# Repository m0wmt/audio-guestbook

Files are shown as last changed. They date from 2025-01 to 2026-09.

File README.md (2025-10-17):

# audio-guestbook
Audio guestbook for an upcoming wedding.  Let guests leave a message so the bride and groom can relive the day and hear what their loved ones/friends had to say via an old BT rotary telephone (using a Teensy development board and a Teensy Audio board) to record messages to a micro SD card.

This project is an update (VSCode + PlatformIO VS Arduino IDE) of the audio guestbook project by [Playful Technology](https://github.com/playfultechnology/audio-guestbook).

## Technical 

### Code Editor
VSCode using the following plugins:
  * PlatformIO
  * Clang-Format (code formatting) with a bespoke .clang-format file

### Coding Standards
Using the [Barr Group](https://barrgroup.com/sites/default/files/barr_c_coding_standard_2018.pdf) embedded C coding standards. Unable to adhere 100% due to clang-format issues and personal preferences, e.g. line length which I prefer to be 120 wide.

### Audio Library
As mentioned in the JOURNAL, the PJRC forum thread on the audio guestbook noted that increasing the number of audio samples in an "audio block" from 128 to 256 mean less writes to the SD card. Audio updates run every 5.8ms rather than the standard 2.9ms, with the consequence that an SD write can take nearly 12ms before an update is "lost".

### Support Projects
- rtc-test Quick test of the RTC with a button battery.
- button-test Poject to test the logic of the audio guestbook without having to worry about messing up the main project.
- admin-monitor An ESP32 project (in progress) that will be used to monitor the status of the audio guestbook via wi-fi. Will only be available if the venue has mains power due to the power demands of wi-fi draining a battery too quickly.

## Requirements
- Power switch to turn recorder on/off
- Start recording when handset is lifted
- Stop recording when handset is replaced
- Light to indicate when recording?
- Maximum recording length of 'n' minutes
- Stop recording after set time, play time exceeded .wav file
- Deal with handset not being put back correctly (see exceed recording length)
- Light to inidicate errors (different colours for different errors)?
- Play recorded message to tell user 'to leave their message after the beep'
- Get recorded message(s) from customer (start recording, exceeding time limit, and contact support)
- Button to replay last message
- Save recorded messages as .wav files to micro SD card
- Indicate how many messages have been recorded (to be defined)
- Power recorder by USB phone charger or battery
- Web page showing status (number of recordings, disk usage etc.) to support user. This will utilize an ESP32 with a Wi-Fi access point, with messages sent via Serial/UART from the Teensy to the ESP32 for displaying. Due to power demand of the wi-fi this will only be available if we're using mains power.

## Parts List
- Rotary telephone [how to dismantle GPO No. 706 Rotary Phone](https://www.britishtelephones.com/t706dismantle.htm)
- Teensy 4.1 [development board](https://www.pjrc.com/teensy/pinout.html)
- Teensy 4.0 [audio board](https://www.pjrc.com/store/teensy3_audio.html)
- Mico SD card (7.2Gb for 24hrs @ 44.1kHz)
- LED light(s)?
- Switch
- ESP32-S3 Mini (Admin Monitor Website)
- [Electret](https://en.wikipedia.org/wiki/Electret_microphone) microphone
- [My 3D model](https://github.com/m0wmt/audio-guestbook/blob/main/notes/GPO706-Electret-Mic.stl) (.stl) of electret microphone housing

<figure>
  <figcaption>Teensy 4.1</figcaption>
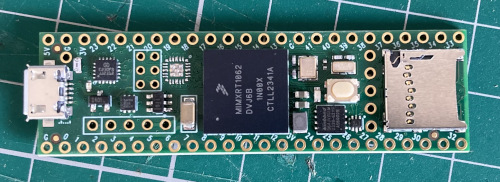
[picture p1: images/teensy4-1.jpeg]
Teensy 4.1 Development Board
  
</figure>

<figure>
  <figcaption>Teensy Audio Board 4.0</figcaption>
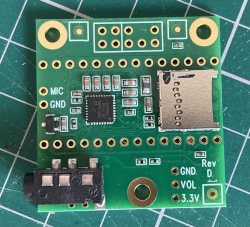
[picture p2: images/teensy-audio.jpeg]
Teensy 4.0 Audio Board
  
</figure>

<figure>
  <figcaption>ESP32-S3 Mini</figcaption>
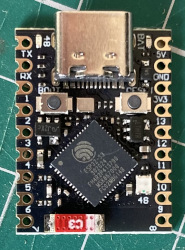
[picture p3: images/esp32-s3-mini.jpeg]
ESP32-S3 Mini Development Board
  
</figure>

<figure>
  <figcaption>GPO No. 706 Rotary Phone</figcaption>
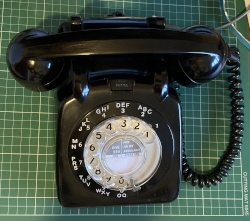
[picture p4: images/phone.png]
GPO No. 706 Rotary Phone
  
</figure>

<figure>
  <figcaption>Phone terminal connections</figcaption>
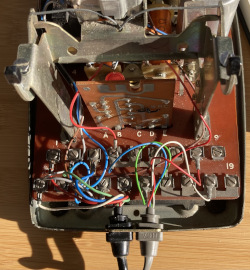
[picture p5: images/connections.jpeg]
Phone terminal connections
  
</figure>

<figure>
  <figcaption>Telephone Microphone</figcaption>
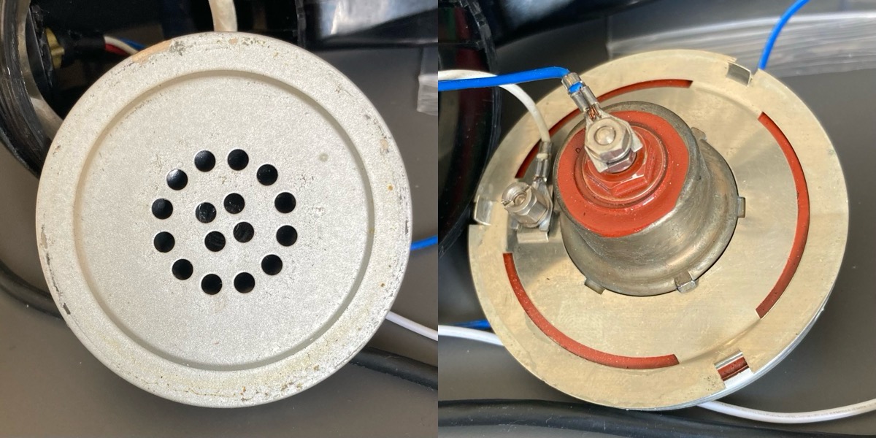
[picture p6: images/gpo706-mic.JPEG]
Telephone Microphone
  
</figure>

<figure>
  <figcaption>Electret Microphone</figcaption>
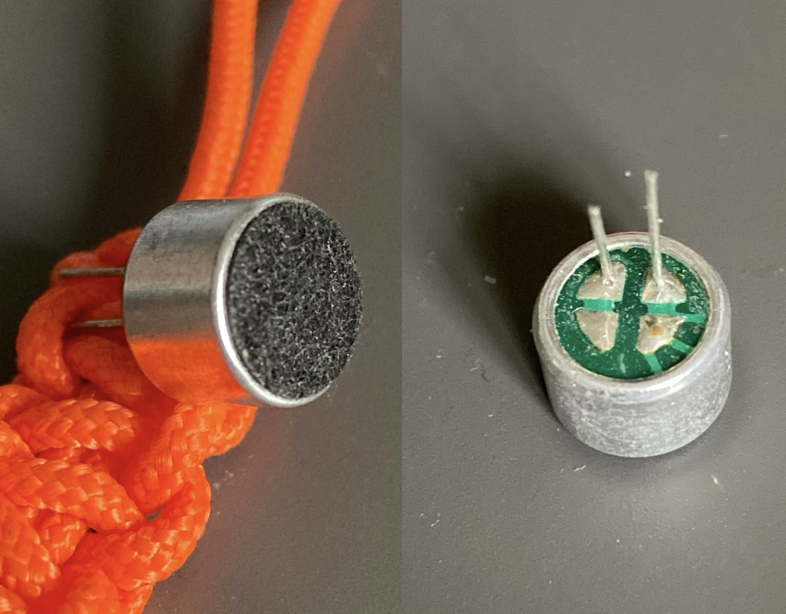
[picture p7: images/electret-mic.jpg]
Electret Microphone
  
</figure>

<figure>
  <figcaption>3D rendering of replacement microphone housing</figcaption>
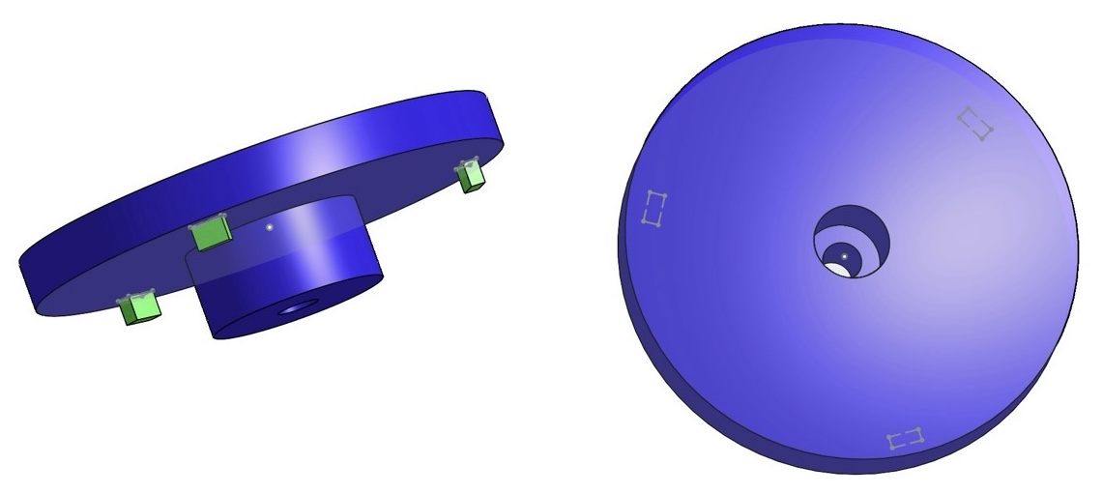
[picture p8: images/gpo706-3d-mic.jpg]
3D rendering of replacement microphone housing
  
</figure>

## Coding Journal
See the [JOURNAL.md](JOURNAL.md) file for a blow-by-blow account of progress etc.

## Wiring
Teensy audio board is connected to the Teensy board through the corresponding pins.  Thank you to my [wife](https://www.redbubble.com/people/quirkytales/shop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) for providing the wiring diagram below.

<figure>
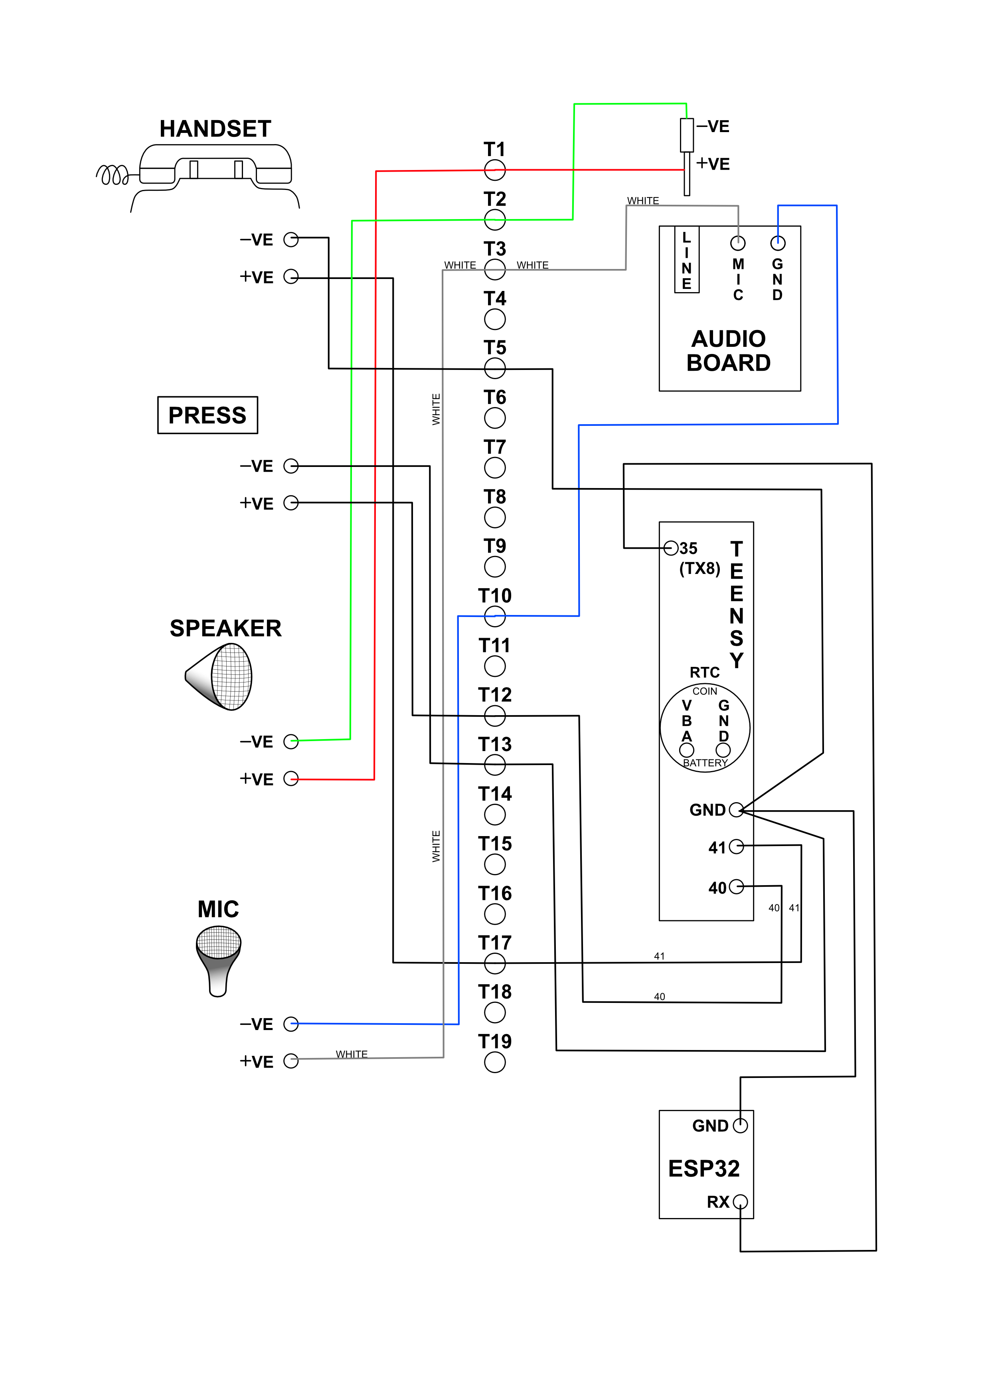
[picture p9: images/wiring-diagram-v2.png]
Wiring Diagram
  
</figure>

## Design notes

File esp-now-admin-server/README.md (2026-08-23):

# esp-now-admin-monitor
This will be the monitoring application for the audio guestbook. It will act as an ESP NOW server and transmit (encrypted) data to the companion application running on an Waveshare ESP32-S3 AMOLED 1.43" round display.

All communication between the Teensy and the ESP will be via UART and one way only, Teensy->ESP, the admin program is not designed to query/control the audio guestbook.

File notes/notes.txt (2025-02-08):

Various notes/useful links from research.

Audio guestbook thread: https://forum.pjrc.com/index.php?threads/teensy-4-0-based-audio-guestbook.70553/

Free RAM: https://forum.pjrc.com/index.php?threads/how-to-display-free-ram.33443/

Teensy Wiki: https://github-wiki-see.page/m/TeensyUser/doc/wiki_index

Memory mapping: https://github-wiki-see.page/m/TeensyUser/doc/wiki/Memory-Mapping

Port mapping: https://github-wiki-see.page/m/TeensyUser/doc/wiki/Mapping-Pins-to-Ports

Teensy Forum:
    https://forum.pjrc.com/index.php#main-category.1
    Audio: https://forum.pjrc.com/index.php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
    UART between Teensy and ESP32: https://forum.pjrc.com/index.php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
    Audio projects: https://forum.pjrc.com/index.php?forums/audio-projects.8/
    Audio guestbook thread: https://forum.pjrc.com/index.php?forums/audio-projects.8/
	
Not compiling issue: https://community.platformio.org/t/teensy-4-0-not-compiling-on-raspberry-pi-bits-c-config-h-no-such-file-or-directory/15592

Teensy example: https://github.com/nickrehm/dRehmFlight/blob/master/Versions/dRehmFlight_Teensy_BETA_1.3/dRehmFlight_Teensy_BETA_1.3.ino

UART between Teensy and ESP32: https://forum.pjrc.com/index.php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

Possible web page app part: https://github.com/rjwats/esp8266-react

ESP32 access point/web server: https://randomnerdtutorials.com/esp32-access-point-ap-web-server/

Issues with original:
    MTP: https://github.com/playfultechnology/audio-guestbook/issues/147
    SD card not detected: https://github.com/playfultechnology/audio-guestbook/issues/116

How to detect rotary dial being used.
    https://www.instructables.com/How-to-turn-an-old-school-rotary-phone-into-an-inp/

    iRotary project: 
    https://www.stavros.io/posts/irotary-saga/ - https://github.com/skorokithakis/iRotary/blob/master/src/sketch.ino

Code examples
--------
## Free RAM
extern unsigned long _heap_start;
extern unsigned long _heap_end;
extern char *__brkval;

int freeram() {
  return (char *)&_heap_end - __brkval;
}

void setup() {
  while (!Serial) ;
  Serial.print("freeram = ");
  Serial.println(freeram());
  volatile char *p = (char *)malloc(152000);
  *p = 0;
  Serial.print("freeram = ");
  Serial.println(freeram());
}

void loop() {
}
---------
	case Mode::Prompting:
      // Wait for users to put the handset to their ear
      wait_start = millis();
      mode = Mode::WaitHandsetEar;
      break;
   
    case Mode::WaitHandsetEar:
      // should check for button changes here, and every case
      if (millis() - wait_start > 1000) // give them a second
      {
        // Play the greeting inviting them to record their message
        playWav1.play("greeting.wav"); 
        mode = Mode::WaitGreetingStart;
      }
      break;
   
    case Mode::WaitGreetingStart:
      if (playWav1.isPlaying()) // WAV file has started playing
      {
        mode = Mode::GreetingIsPlaying;
      }
      break;

    case Mode::GreetingIsPlaying:
      // Wait for greeting to end OR handset to be replaced
      if (playWav1.isPlaying()) // still playing
      {
        // Check whether the handset is replaced
        buttonRecord.update();
        if(buttonRecord.fallingEdge())
        {
          // Handset is replaced
          playWav1.stop();
          mode = Mode::Ready;
          // return; // NO NO NO!
        }
      }
      else
      {
        waveform1.frequency(440);
        waveform1.amplitude(0.9);
        wait_start = millis();
        mode = Mode::PlayingGreetingBeep;
      }
      break;
   
    case Mode::PlayingGreetingBeep:
      if (millis() - wait_start > 250) // 250ms beep
      {
          // beep is done, stop it
          waveform1.amplitude(0);
          // Start the recording function
          startRecording();
      }
      break;
-------
Beeps

void end_Beep(void) {
	waveform1.frequency(523.25);
	waveform1.amplitude(beep_volume);
	wait(250);
	waveform1.amplitude(0);
	wait(250);
	waveform1.amplitude(beep_volume);
	wait(250);
	waveform1.amplitude(0);
	wait(250);
	waveform1.amplitude(beep_volume);
	wait(250);
	waveform1.amplitude(0);
	wait(250);
	waveform1.amplitude(beep_volume);
	wait(250);
	waveform1.amplitude(0);
}

void two_tone_Beep(void) {
	waveform1.frequency(523.25);
	waveform1.amplitude(beep_volume);
	wait(250);
	waveform1.amplitude(0);
	waveform1.frequency(375.0);
	wait(250);
	waveform1.amplitude(beep_volume);
	wait(250);
	waveform1.amplitude(0);
	waveform1.frequency(523.25);
	wait(250);
	waveform1.amplitude(beep_volume);
	wait(250);
	waveform1.amplitude(0);
	waveform1.frequency(375.0);
	wait(250);
	waveform1.amplitude(beep_volume);
	wait(250);
	waveform1.amplitude(0);
}

from here: https://forum.pjrc.com/index.php?threads/audio-guestbook-teensy-4-1-please-help.71440/#post-315408

Forum post on guestbook: https://forum.pjrc.com/index.php?threads/teensy-4-0-based-audio-guestbook.70553/

Ringing telepohone: https://www.britishtelephones.com/wavs/ring706.wav

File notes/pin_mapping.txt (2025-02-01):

Teensy 4.1 Pin to GPIO port mapping results.

PIN   GPIOn-BITm  |  GPIOn-BITm    PIN
------------------|-------------------
00  -> GPIO6-03   |   GIPO6-02  ->  01
01  -> GPIO6-02   |   GIPO6-03  ->  00
02  -> GPIO9-04   |   GIPO6-12  ->  24
03  -> GPIO9-05   |   GIPO6-13  ->  25
04  -> GPIO9-06   |   GIPO6-16  ->  19
05  -> GPIO9-08   |   GIPO6-17  ->  18
06  -> GPIO7-10   |   GIPO6-18  ->  14
07  -> GPIO7-17   |   GIPO6-19  ->  15
08  -> GPIO7-16   |   GIPO6-20  ->  40
09  -> GPIO7-11   |   GIPO6-21  ->  41
10  -> GPIO7-00   |   GIPO6-22  ->  17
11  -> GPIO7-02   |   GIPO6-23  ->  16
12  -> GPIO7-01   |   GIPO6-24  ->  22
13  -> GPIO7-03   |   GIPO6-25  ->  23
14  -> GPIO6-18   |   GIPO6-26  ->  20
15  -> GPIO6-19   |   GIPO6-27  ->  21
16  -> GPIO6-23   |   GIPO6-28  ->  38
17  -> GPIO6-22   |   GIPO6-29  ->  39
18  -> GPIO6-17   |   GIPO6-30  ->  26
19  -> GPIO6-16   |   GIPO6-31  ->  27
20  -> GPIO6-26   |   GIPO7-00  ->  10
21  -> GPIO6-27   |   GIPO7-01  ->  12
22  -> GPIO6-24   |   GIPO7-02  ->  11
23  -> GPIO6-25   |   GIPO7-03  ->  13
24  -> GPIO6-12   |   GIPO7-10  ->  06
25  -> GPIO6-13   |   GIPO7-11  ->  09
26  -> GPIO6-30   |   GIPO7-12  ->  32
27  -> GPIO6-31   |   GIPO7-16  ->  08
28  -> GPIO8-18   |   GIPO7-17  ->  07
29  -> GPIO9-31   |   GIPO7-18  ->  36
30  -> GPIO8-23   |   GIPO7-19  ->  37
31  -> GPIO8-22   |   GIPO7-28  ->  35
32  -> GPIO7-12   |   GIPO7-29  ->  34
33  -> GPIO9-07   |   GIPO8-12  ->  45
34  -> GPIO7-29   |   GIPO8-13  ->  44
35  -> GPIO7-28   |   GIPO8-14  ->  43
36  -> GPIO7-18   |   GIPO8-15  ->  42
37  -> GPIO7-19   |   GIPO8-16  ->  47
38  -> GPIO6-28   |   GIPO8-17  ->  46
39  -> GPIO6-29   |   GIPO8-18  ->  28
40  -> GPIO6-20   |   GIPO8-22  ->  31
41  -> GPIO6-21   |   GIPO8-23  ->  30
42  -> GPIO8-15   |   GIPO9-04  ->  02
43  -> GPIO8-14   |   GIPO9-05  ->  03
44  -> GPIO8-13   |   GIPO9-06  ->  04
45  -> GPIO8-12   |   GIPO9-07  ->  33
46  -> GPIO8-17   |   GIPO9-08  ->  05
47  -> GPIO8-16   |   GIPO9-22  ->  51
48  -> GPIO9-24   |   GIPO9-24  ->  48
49  -> GPIO9-27   |   GIPO9-25  ->  53
50  -> GPIO9-28   |   GIPO9-26  ->  52
51  -> GPIO9-22   |   GIPO9-27  ->  49
52  -> GPIO9-26   |   GIPO9-28  ->  50
53  -> GPIO9-25   |   GIPO9-29  ->  54
54  -> GPIO9-29   |   GIPO9-31  ->  29

Above generated by:
#include <Arduino.h>
#include <Wire.h>

/* Headers to map pins to ports */
#include <algorithm>
#include "pin.h"

static void map_pins_to_ports(void);

/**
 * @brief Display GPIO registers to the digital pins and vice versa.
 */
static void map_pins_to_ports(void) {
    Pin *pins1[CORE_NUM_DIGITAL];
    Pin *pins2[CORE_NUM_DIGITAL];

    for (unsigned pinNr = 0; pinNr < CORE_NUM_DIGITAL; pinNr++)
    {
        Pin *p = new Pin(pinNr);
        pins1[pinNr] = p;
        pins2[pinNr] = p;
    }

    std::sort(pins1, pins1 + CORE_NUM_DIGITAL, [](Pin *a, Pin *b)  // Sort by pin number
    {
        return a->getPinNr() < b->getPinNr(); 
    }); 

    std::sort(pins2, pins2 + CORE_NUM_DIGITAL, [](Pin *a, Pin *b)   // Sort by GPIO and Bit
    {
        if (a->getGpioNr() < b->getGpioNr()) return true;
        if (a->getGpioNr() > b->getGpioNr()) return false;
        if (a->getBitNr() < b->getBitNr())   return true;
        return false;
    });

    // Print results in two columns--------------------------
    Serial.println("PIN   GPIOn-BITm  |  GPIOn-BITm    PIN");
    Serial.println("------------------|-------------------");
    for (unsigned i = 0; i < CORE_NUM_DIGITAL; i++)
    {
        unsigned pin1 = pins1[i]->getPinNr();
        unsigned pin2 = pins2[i]->getPinNr();
        unsigned gpio1 = pins1[i]->getGpioNr();
        unsigned gpio2 = pins2[i]->getGpioNr();
        unsigned bit1 = pins1[i]->getBitNr();
        unsigned bit2 = pins2[i]->getBitNr();
        Serial.printf("%02d  -> GPIO%u-%02u   |   GIPO%u-%02u  ->  %02d\n", pin1, gpio1, bit1, gpio2, bit2, pin2);
    }    
}

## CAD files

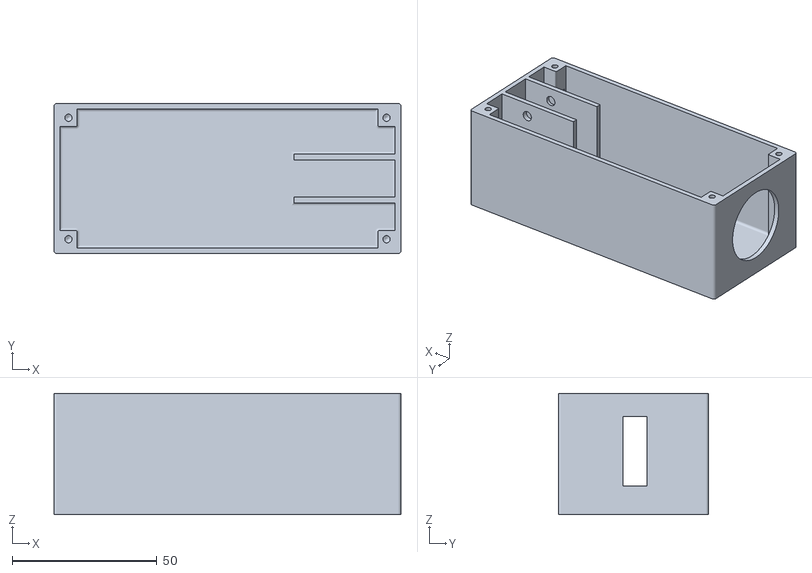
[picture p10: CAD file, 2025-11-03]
notes/AG Power Box.stl
120.0 x 52.0 x 42.0

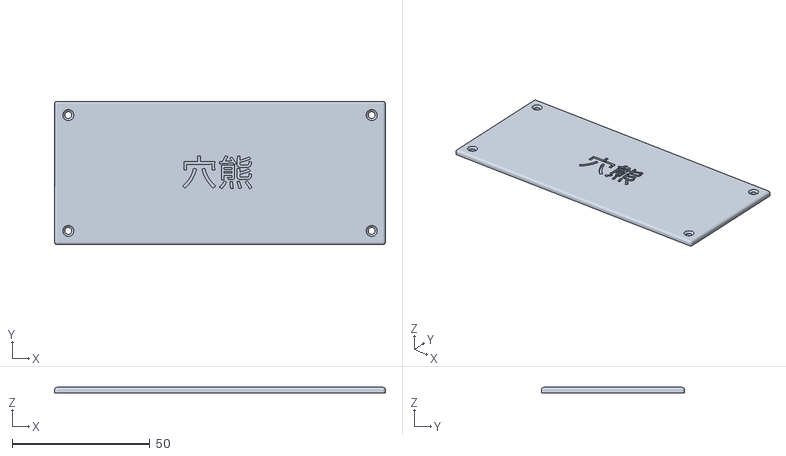
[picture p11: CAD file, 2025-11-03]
notes/AG Power Box Lid.stl
120.0 x 52.0 x 2.00

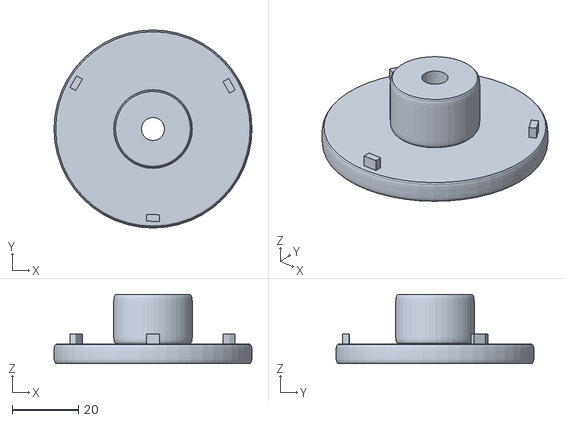
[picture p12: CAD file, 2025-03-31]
notes/GPO706-tinkercad.stl
59.9 x 59.9 x 21.0

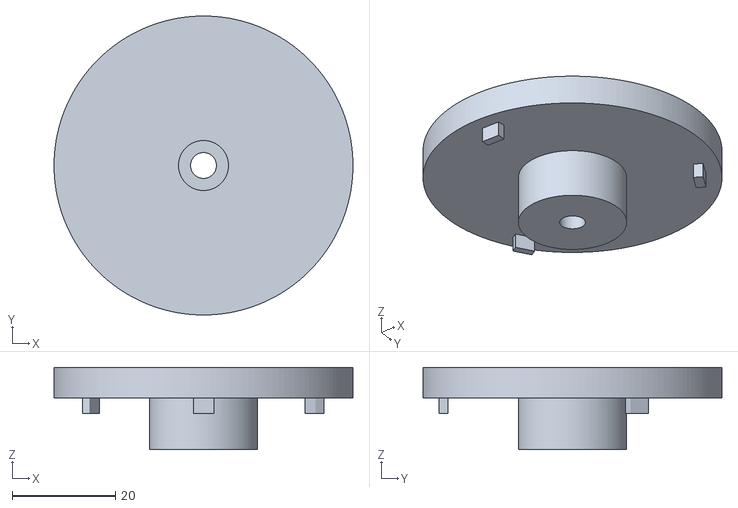
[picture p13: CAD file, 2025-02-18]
notes/GPO706-Electret-Mic.stl
58.0 x 58.0 x 16.0

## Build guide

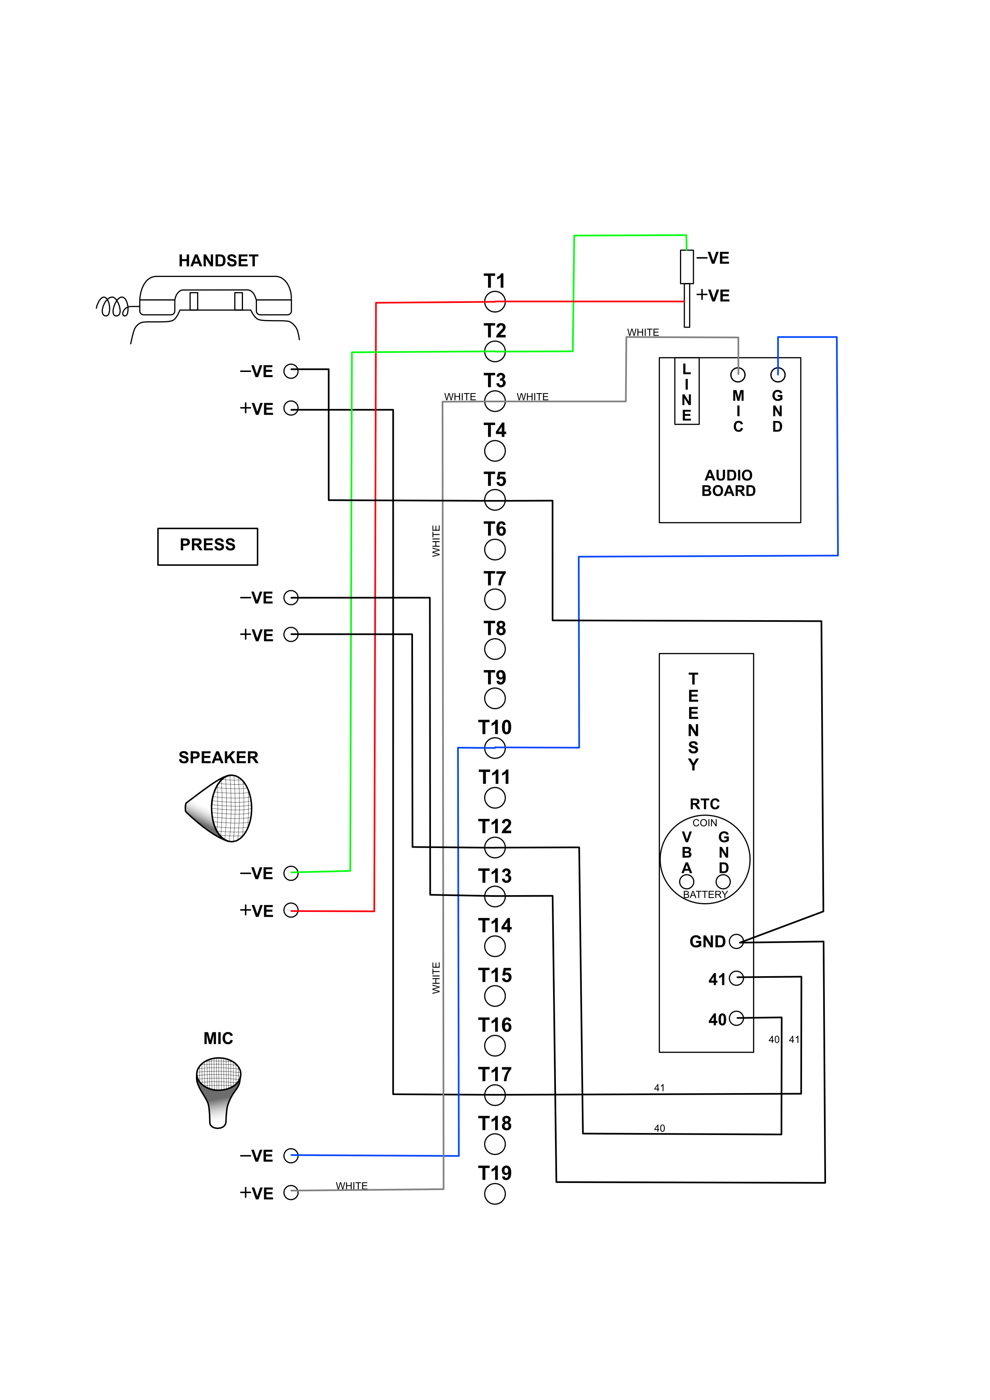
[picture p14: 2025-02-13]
images/wiring-diagram.png

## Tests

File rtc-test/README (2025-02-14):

This directory contains the rtc-test program to set the time and read the RTC. Like to try out ideas before adding them to the main program.

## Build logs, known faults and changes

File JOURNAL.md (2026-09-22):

# Audio Guestbook Journal

This journal will be a log/diary of the audio guestbook journey.

An audio guestbook is a unique and fun way to capture audio messages from guests during an event, it this case an upcoming wedding.

Plan: Use an old GPO rotary telephone (containing new electronics) that guests can leave messages on for the bride and groom to hear later and have as a memory of the day.

### January

Ordered a Teensy 4.1 embedded development board and a Teensy 4.0 audio board for the audio processing of the messages.
 
Soldered headers and pins to the two boards so they can be connected together.

Set up the development environment (linux development mini PC), using VSCode and the PlatformIO extension. All code available in it’s own [github repository](https://github.com/m0wmt/audio-guestbook). Created a ‘blink’ program to prove that it all works as expected.

### February

Rotary Telephone:
Rotary Telephone

Won an eBay auction for a GPO No. 760 rotary telephone. In very good condition, rotary dial works perfectly bringing back nostalgic memories and it has an additional PRESS button.

Started writing test code to confirm soldering was okay and that we can access the SD card on the Teensy (main board) and play WAV files via the Teensy audio board, all working as expected.

Took the phone to pieces; removed the two screws on the top where the handset rests and pulled the top off.  Identified all the wires; microphone, speaker, handset rocker switch, and the PRESS button switch.

> Speaker: 			Green == 2 (-ve GND) 		Red == 1 (+ve TIP)
> 
> Microphone: 		Blue == 3 (-ve GND) 		White == 10 (+ve MIC)
> 
> Handset Switch: 	5 (-ve GND)				   17 (+ve)
> 
> PRESS Button: 	Brown == 13 (-ve GND)	 	Blue == 12 (+ve)

Phone speaker connected to Teensy Audio Board:
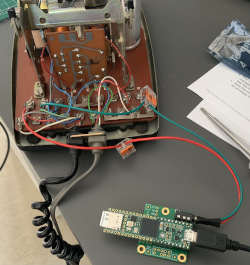
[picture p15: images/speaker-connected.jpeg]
Speaker connected to Teensy


Found a spare 3.5mm headphone, stripped it of it’s existing wiring and re-wired with 2 wires, one at the tip (red/+ve) and one on the sleeve (green/GND). Plugged it in to the audio board headphone socket and tested, can now hear music from the telephone handset via code.

Phone connection panel:
Phone connections

Identified and tested the handset switch and PRESS button actions.  Can now detect PRESS button being pressed/released and handset rocker switch when the handset is lifted/put back down. Using pins 40 and 41 on the Teensy for the two switches, 41 for the handset and 40 for the PRESS button.
Wiring of the telephone; Handset lever, Teensy GND to terminal 5 (T5) on the handset, +VE (Teensy pin 41) to T17 on the handset. PRESS button, Teensy GND to T13, +VE to (Teensy pin 40) T12.

Can play a .WAV file but not a beep via code!  Checking the pins I'd soldered it looks as though I haven't soldered the VOLUME pin for the audio board, added extra pins to the Teensy board so that all pins are connected to the audio board.  Switched everything back on and got the red LED blinking at me :-(. Not sure what I've done wrong, blinks 9 times which apparently can have something to do with onboard memory, bottom of this page has a [list of blink error codes](https://www.pjrc.com/store/ic_mkl02_t4.html).  There's also a list of known problems available [here](https://www.pjrc.com/teensy/troubleshoot.html).  One way to attempt a fix apparently is press the load button for 15 seconds and then release, this should cause the chip to reset (red LED will be on whilst this happens, can take about 40 seconds) and reload the blink program.  Tried this a few times and eventually got it to work, orange LED is blinking every 500ms, next test will be a simple prgram just in case it's the beep code I was trying out caused the issue. If one exists you can view the crash report by;
```
void setup() {
    while(!Serial) {
    }
    if (CrashReport)
        Serial.print(CrashReport);
}
```

Connected a new 3.3v button battery to the RTC ([VBAT + GND](https://www.pjrc.com/teensy/card11b_rev4_web.pdf) next to the SD card on the Teensy) today (7th Feb) and wrote a test program to set and read the RTC.  All seems to work, will leave the battery connected and test to see how long it lasts, according to the [PRJC Teensy forum](https://forum.pjrc.com/index.php) about 1-2 months for the Teensy 4.

Finally fixed the issue with no beep from the speaker, wasn't initalising the mixer section properly, RTFM!  Added RTC code to main program.

Not getting any voice when trying to record, not getting anything to record, just writing out the header!

Fixed the recording issue, hadn't connected an audio input (from the microphone) stream to the output queue (in code), had connected the speaker by mistake to the queue!  Testing micGain(40) values for the recordings, haven't decided on the best value yet. Replaying the .wav files in Audacity gives a good visual indication of how much gain is too much. Have ordered some electret microphones to see if they are better than the telephones original one, should be an easy swap if they're better.

Electret microphones have arrived (via eBay for a couple of quid) and seem to give a cleaner voice recording, though this will need to be tested in the phone handset to confirm at some point.

Tidy up code a bit and start to document functions. Modified AUDIO_BLOCK_SAMPLES to 256 in /home/#########/.platformio/packages/framework-arduinoteensy/cores/teensy4/AudioStream.h as suggested by the audio guestbook post on the PRJC forum. Did a full clean and rebuild of project and changes are picked up - as this will probably be the only Teensy audio project I do changing the library is fine for now.

Now working on phone handset logic and coding standards, attempting to keep as close to the [Barr Group](https://barrgroup.com/sites/default/files/barr_c_coding_standard_2018.pdf) coding standards as I'm happy with.  For a bit of fun added morse code for error sounds, that way will be able to understand what the error is as we won't be able to see the Teensy LED with the phone back together. Will worry about PRESS button and dialer after happy with this logic.

Now have a wiring diagram of all the connections thanks to my [wife](https://www.redbubble.com/people/quirkytales/shop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) who is a digital artist amongst other talents.

Have decided to write a test button (button-test) program to work out the handset and press button logic, less to worry about with recording etc. Have seen a variety of ideas on the Teensy forum which I want to try out/test. Button-test project now created (14th Feb) within the audio-guestbook project, updated the platformio.ini file so that I can easily compile either project inside VSCode. Have already found a logic error and expect to find others.

Modified logic, using less switch options in the main loop and removed looking at buttons during the wait() function. Need to sort out too long recordings (need to confirm how long a message may be), not erroring for some reason, had to stop for the day before I could fix it.

Still working on recording logic/errors but for a bit of variety I decided to model a microphone housing for the electret microphone to replace the telephones original microphone. This is my first proper attempt at 3D modelling and I used [Onshape](https://www.onshape.com/en/) because it can be used on a variety of platforms and is free for hobbyists. First rendition looks good, now need to wait for my 3D print manufacturer to print it. An .stl of the model is available in the notes directory of this repository, I will put it on [thingiverse](https://www.thingiverse.com/) once I'm happy with it. TODO: ADD THINGIVERSE LINK TO .STL

3D model of replacement microphone: 3D Model

Have too long recording sorted. Sound a tick every second for the last 15 seconds and then end the recording. Will need a leaflet letting people know how long they can have to record a message. If phone is left off the hook for some reason morse code (SOS) will play via the handset speaker until the handset is replaced.

Think I have all the recording logic sorted now, just needs lots of testing to make sure!!  Have now copied relevant code from the button-test project to the main project. One issue I am having during testing is that when I play a beep to warn the user that their time is running out that appears on the recording as well - no idea why. Need to try the electret microphone plugged directly into the audio board and some headphones I have lying around to see if there is any crossover via the phone connections.

Might need to replace the handset rocker switch, seems very noisy or there are multiple connections on the phone causing noise issues or change pin connections so I don't go through the 'T' connection on the phone.

Did a test of the handset microphone vs the electret microphone and direct wiring without the telephone patch connections on the phone base. As you can see from the pictures below, the electret microphone has a clearer signal and with no wiring going through the phone connection plate no warning beeps appear in the last 'n' seconds of the extended recording.

Handset microphone and warning spikes near the end showing the warning beep also being recorded. Handset Microphone

Electret microphone; clearer audio, and no warning spike feedback recorded. Handset Microphone

Have now removed the handset connections (all 4) from the 'T' connector on the telephone motherboard and soldered/wired them directly to the Teensy Audioboard for hopefully clearer sound/voice recording. Waiting on 3D model of the microphone before I swap the original out for the Electret one.

Now just a case of more testing to see what errors I can generate and think about how to power the telephone/Teensy etc. if there isn't a power socket available. Need to run a test on how much power it uses for say 12 hours.

Testing going well, for something different going to move to admin monitor program.

Using an ESP32-S3 mini MCU may not be the best, having issues with Linux and USB after writing firmware with this board. Need to remove the USB cable and re-attach it then run the serial monitor to get access to the serial output. For some reason the board isn't rebooting after the upload, or if it is the monitor isn't seeing it! Other than that the wi-fi access point works, just need to design the web page I'll be displaying, have a few ideas. It will be a view only program, don't want any chance of someone cocking up the Teensy by sending a message to it. 

3D model for microphone placement arrived, was resin printed. I didn't quite get the location of the tabs at the bottom far enough out to stop it rotating, once it's in position I'll decide if this is a problem or not. Microphone fits in nicely (after a tiny bit of fettling) in the model once I drilled the big hole out to 10mm. Had set it at 9.7mm (the size of the microphone) but tolerances were too tight! Need to update the model at some point, will try using OpenSCAD for a change.

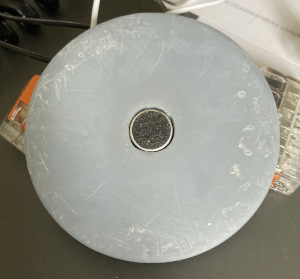
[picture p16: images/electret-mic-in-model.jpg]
Mic in place
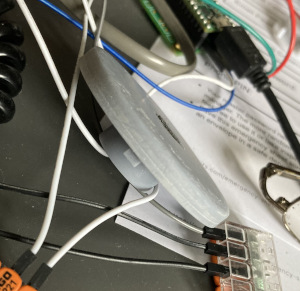
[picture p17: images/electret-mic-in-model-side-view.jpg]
Side view
 

Spent some time on the guestbook monitor program today, takes longer than you think to create an access point web page! Now have a web page via the ESP32 which updates every 30 seconds (currently) giving you and overview of the firmware status, number of recordings and disk space left on the SD card.

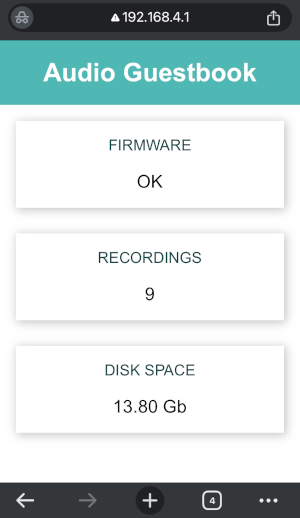
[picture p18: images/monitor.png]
Monitor


Need to work now on connecting the Teensy and ESP32 so that the Teensy can update the ESP32 (if it's connected/running) with it's status, disk space and number of recordings. Might add other information but that's the minimum I want for now.

Had a thought about the venue not having mains power available where the phone will be, instead of wi-fi for the monitor program can I use BLE, the answer is yes. Will have to host the web page to view the status of everything on github pages - so I don't corrupt my current repository I will be making a new repository for the monitor web page, once I've done this I'll update this journal with the location. No idea if I'll use this or the wi-fi or if it'll work but worth a try and I'll learn something new!

Trying out a new 3D modeling tool - Tinkercad - which can be run on an iPad. Not as powerful as OnShape or computer based 3D packages but for what I need here works just fine. A new .stl file is available in the notes directory (helpfully named tinkercad in the file name!). Yet to be printed so no idea if it's more accurate than the first model but it's there for later testing.

Been a little while - took a break as the weather has been nice!.  Yesterday (15/4/25) I replaced the original microphone with the electret microphone in the phone, soldered in place but can be removed and the original put back in if ever needed. Recordings are good so that's another step closer and the 10 second warning beeps are effectively gone - <audio controls src="./audio/output.wav"></audio> <a href="./audio/output.wav"> example sound file</a>.

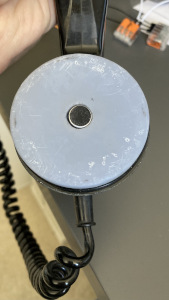
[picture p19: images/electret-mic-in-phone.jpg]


Created new admin monitor program for low energy bluetooth, can read the test values on my phone using the nRF Connect app available on the Android/iPhone stores.

Been a while but starting to work now on the admin monitor. Using serial8 on the Teensy (pin 34/35) as the other pins are being used/obscured by the audio board.  The monitor will only receive information from the teensy, it will not be able to transmit to it as I don't want anyone messing with the guestbook.

Eventually had some time to work on the admin monitor.  Now that we have batteries available (2 x 24v from an electric buggy) I am going to concentrate on the wi-fi option for
the admin application as I like the view I can show on my phone.  Will need to test at some point how far wi-fi will reach from an ESP32. 

Wi-fi version now working. Sending data from the Teensy via Serial8 to the ESP32 and then displaying the information on the web page that the ESP32 is publishing.  Could do more on it but it's working so happy for now. 

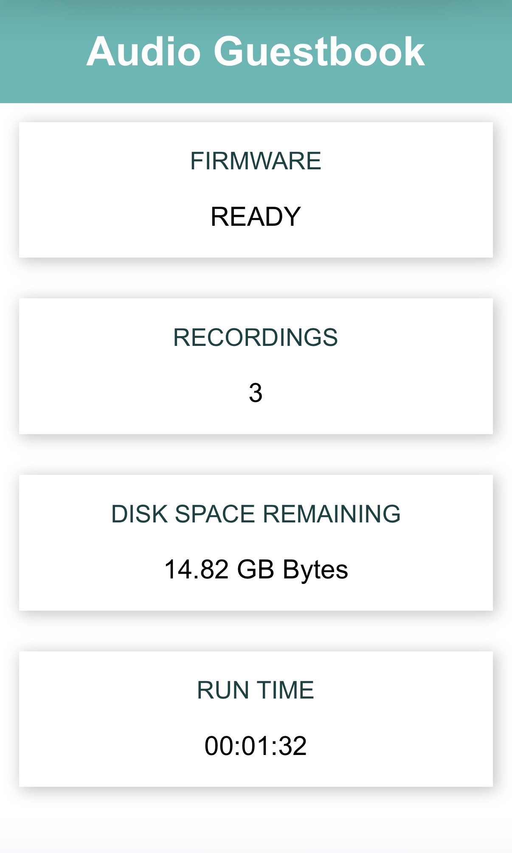
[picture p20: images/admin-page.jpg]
Admin Page


Haven't been able to upload to the Teensy reliably since a Linux (Mint) update so started up the Windows laptop and worked on there for the Teensy part.  Not sure if it was the update that stopped it working (USB issues) but spent too much time trying to get it to work so went the easy route for now. 

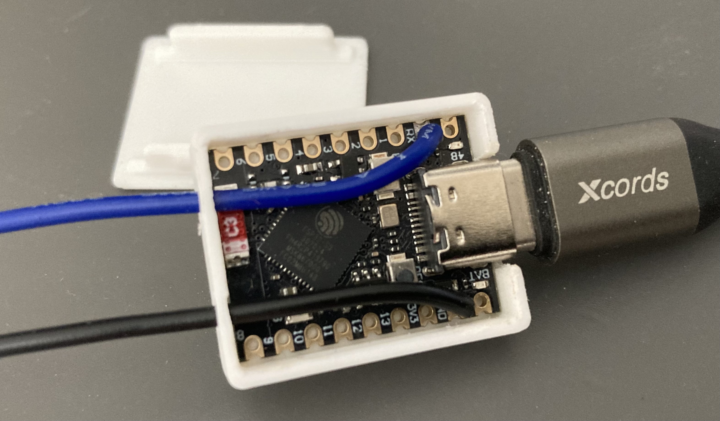
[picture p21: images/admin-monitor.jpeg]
Admin Monitor ESP32
Soldered the admin monitor ESP32 with the 2 wires required, UART RX (from Teensy TX) and the common GND between the ESP32 and the Teensy.  Need to talk to my electrical drawer for a new circuit :-).  Fitted it in a nice small case that I printed on our Elegoo Centauri Carbon 3D printer so it'll be electrically safe when inside the phone encloser.  Used a model created by [pm3dka](https://www.thingiverse.com/thing:6653126) on thingiverse.  

Thanks to my [wife](https://www.redbubble.com/people/quirkytales/shop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) for the new wiring diagram now with the ESP32 connections included.

Currently (October 2025) designing (with OnShape) a box that I will 3D print to connect the 24v battery we now have available to the boards via a cigarette lighter with a USB charging connector.  Images to follow once this has been perfected, currenlty in the test stage to get the size right.

Now November 2025; Battery connection box designed (STL files available in the /notes directory) and printed.  Also tested the battery (2x12v in series) connector with the cigarette lighter and both the Teensy and ESP32 powered from it, all working as it should do.  Will probably just use 1 battery at a time (no idea yet if both will be needed on the day or not, have 4 available) as this uses less power (and less heat) to convert from 12v to 5v vis 24v to 5v.  Need to calculate the power draw of both boards before deciding on what battery(s) to use.

Power connection box - open:

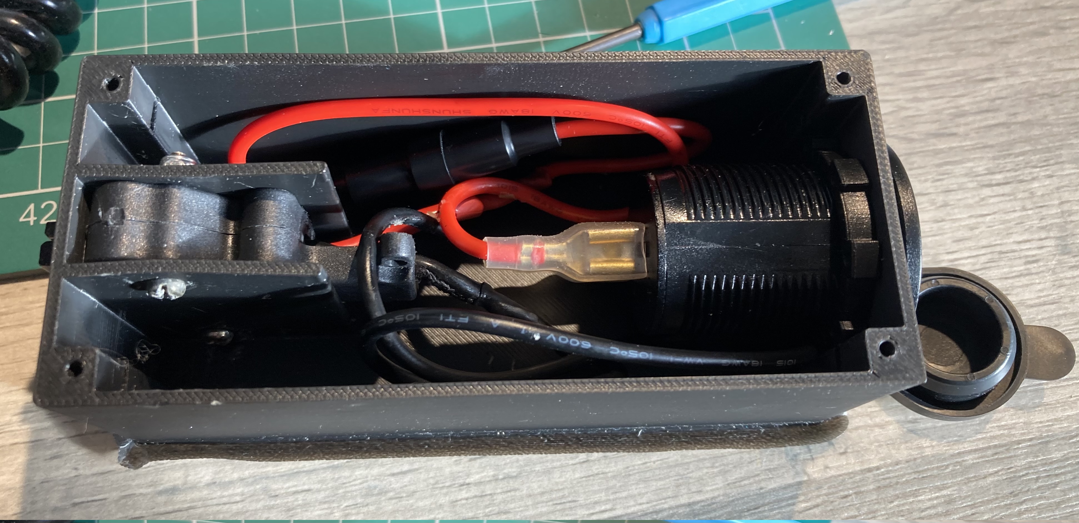
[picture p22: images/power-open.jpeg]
Power Connection Box - Open


Power connection box - battery connector: 

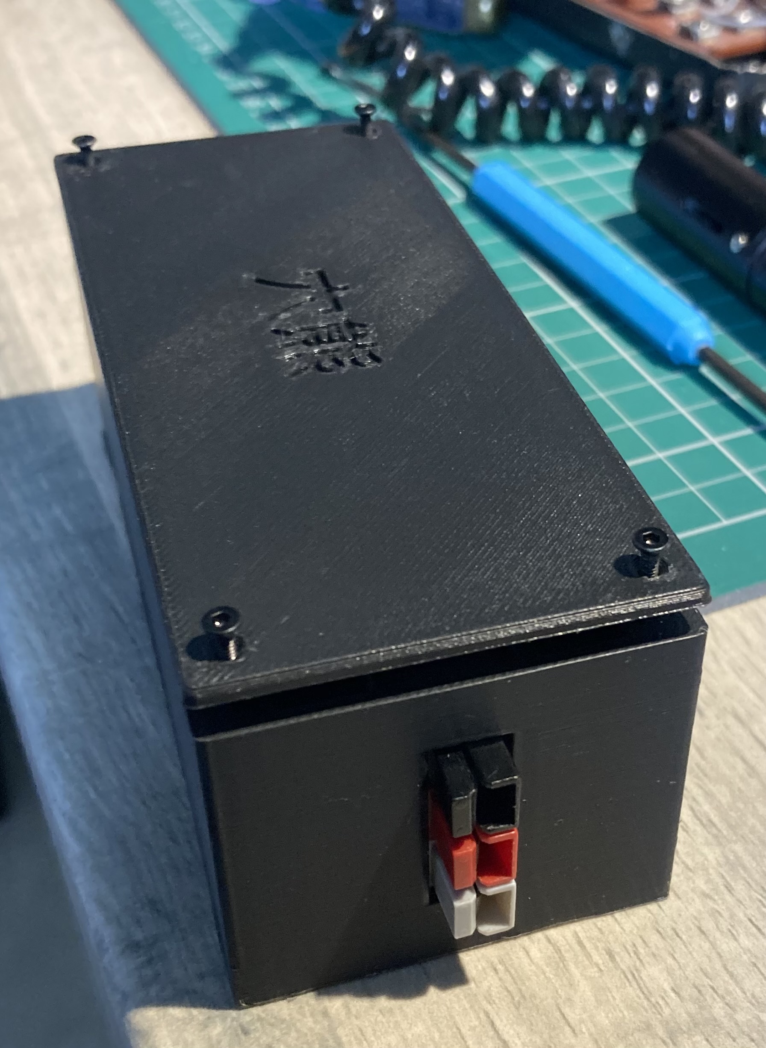
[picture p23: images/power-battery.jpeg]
Power Connection Box - Battery Connector


Power connection box - cigarette lighter -> Teensy/ESP32: 

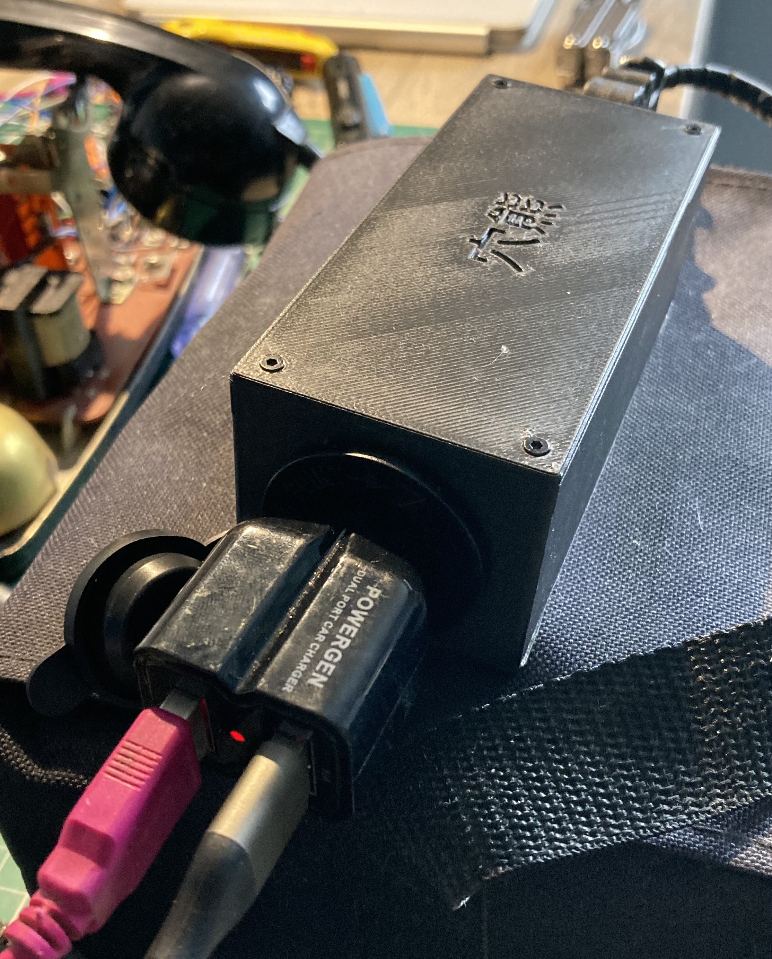
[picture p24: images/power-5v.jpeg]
Power Connection Box - Teensy/ESP


A couple of design issues with the power connection box that I'd redesign if I had to do it again but overall I'm happy with the outcome.  Now waiting on a [connection crimper](https://www.amazon.co.uk/IWISS-Crimping-0-08-1-0-Ratcheting-Connector/dp/B01N4L8QMW) and some [Dupont connectors](https://www.amazon.co.uk/YIXISI-Connector-Replacing-Repairing-Connectors/dp/B08JV8G5YN) so I can wire up the phone to the micro processors. 

Crimper arrived; crimping small wires in to small connectors is not the easiest thing to do!  20AWG wires in to the Dupont connectors works but putting them in to the connectors isn't so easy, for that and 18AWG bigger connectors are needed.  Crimping photo's for completeness :-)

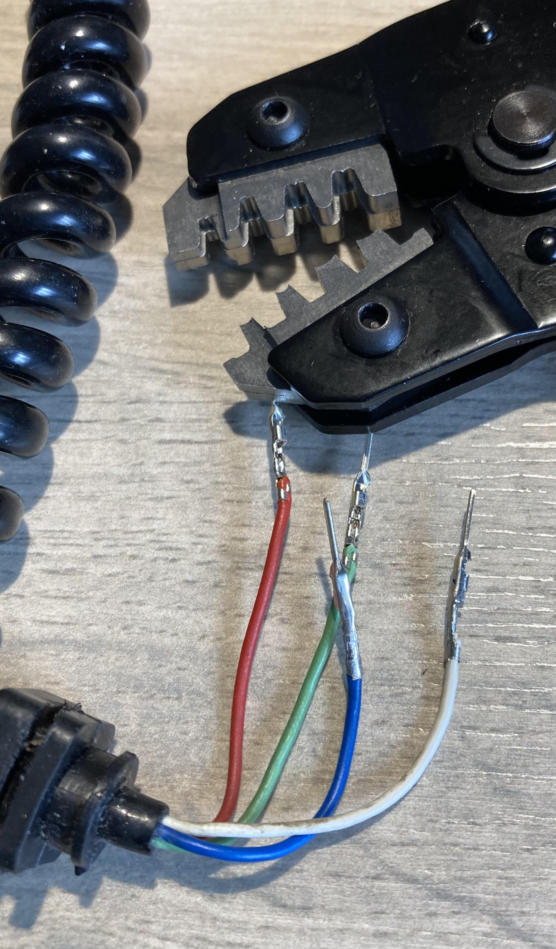
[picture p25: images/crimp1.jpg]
Crimp No.1
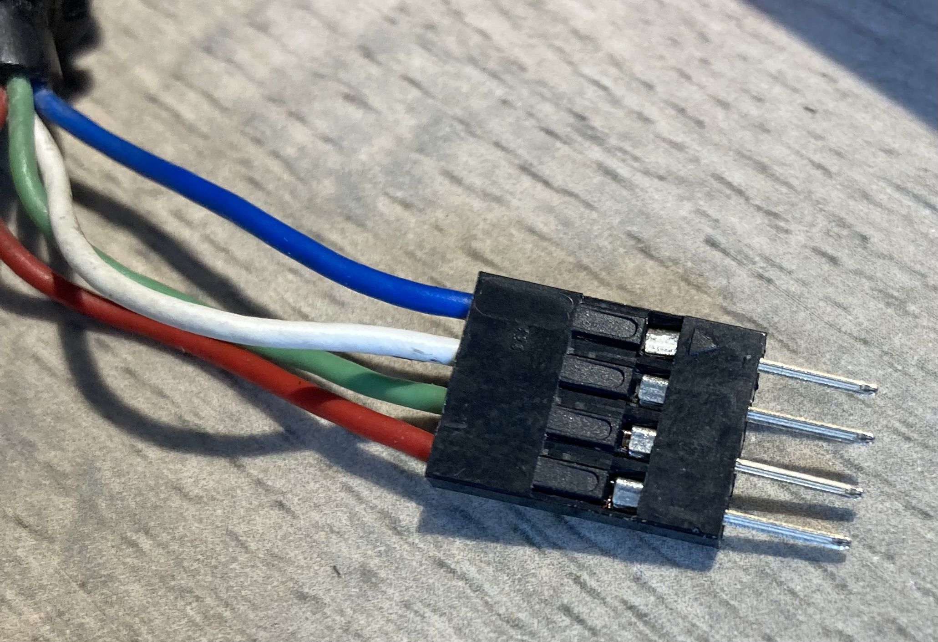
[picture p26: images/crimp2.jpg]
Crimp No. 2
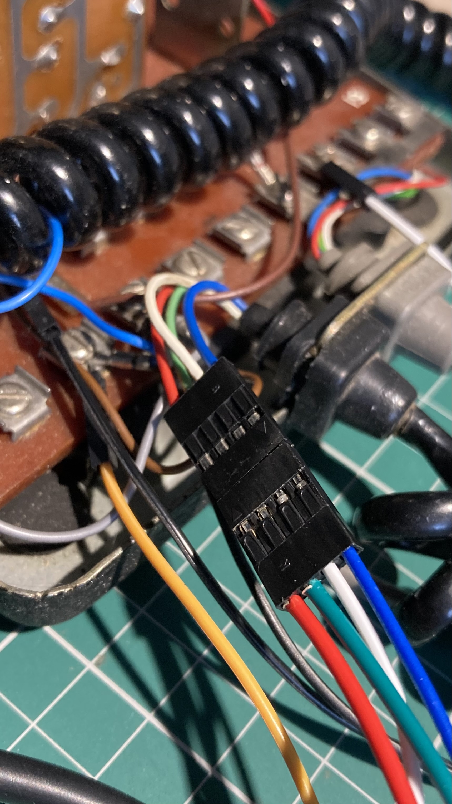
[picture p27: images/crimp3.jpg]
Crimp No. 3
  

Now all I need to do is to try and fit everything back in to the phone and put the case on for next phase of testing - does fit but a bit tight.  

Of the 4 x 12v batteries I have 3 of them seem to be okay (12.5v +) and one isn't so well (7.6v), just need to find a 12v battery charger (the one that came with the batteries is 24v) to see if we can rescue it.

Had a look at bluetooth monitor but having issues with phone when I turn bluetooth on/off, doesn't reconnect to bluetooth on the ESP32 - probably something I'm not doing right!  Checked that WiFi option was still working, had a slight issue with the status message, spelt the flag in the index.h file wrong so it wasn't updating, fixed now :-)  Had a look at slowing the speed of the ESP32, it's only showing a web page to me so not doing much and slowing it down will save some power.  Changed the speed in the platform.ini file, could do it in code (which I did first) but here seems like the best place for it.

July 2026; Now have a voice recording from the future Mr & Mrs to play when the phone is picked up.  Also reduced the recording time of a message to 3 minutes.

August 2026; Currently carrying out testing.  Have added an error message for leaving the handset off the hook to show when this happens in the admin monitor.  Admin monitor is currently running it's own web server to host the web page, will have a look if we could use a phone hotspot instead so that we don't have to keep changing the wifi on the phone.  Own web page is better in that you don't need internet access if you're in the middle of nowhere.  
 
Update: Testing has gone well and no problems, even with loud music/voices when recording messages.  Have added a different monitor application using Espressif’s ESP-NOW protocol for communication; esp-now-admin-server on the ESP32 inside the phone and audio-guestbook-admin-viewer on a 
Waveshare ESP32-S3 1.43" AMOLED round display to show phone data.  Much easier to use than a phone all the time.

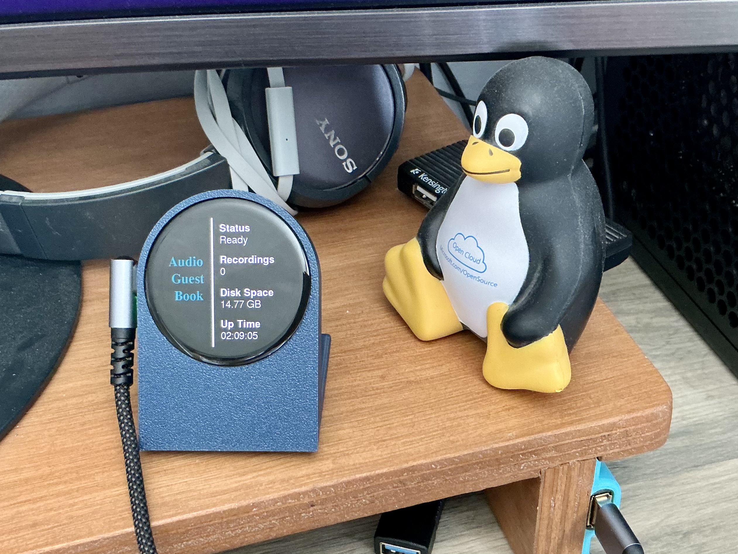
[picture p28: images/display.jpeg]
Round Display


September 2026; Have created a new admin monitor display inspired from a car's speedometer. Has an arc showing the number of recordings and a fuel gauge showing how much disk space is available. Some pictures below, not the best colour reproduction but there to give an idea. 

Recording

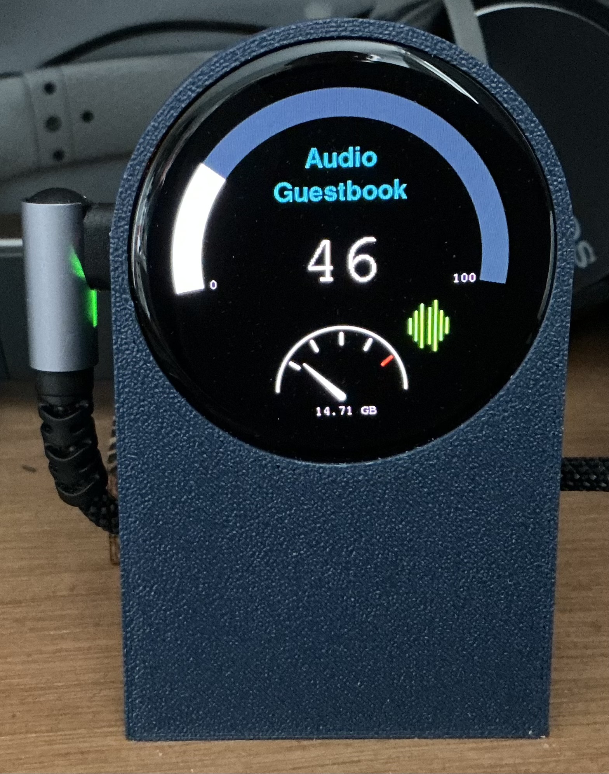
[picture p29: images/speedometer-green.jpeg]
Recording


Phone off the hook

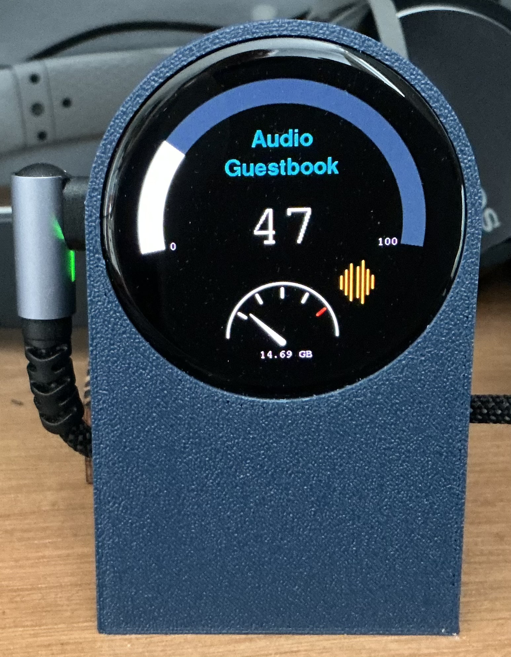
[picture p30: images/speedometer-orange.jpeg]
Off the hook


Error

Recording

Have also updated the ESP32 admin program to get the number of recordings when it is switched on so that the viewer shows the correct number of recordings if the phone has been used elsewhere, e.g. during wedding prep!  Added a nicer font for the number of recordings, didn't like the old one!

### Development Tasks:
* Play .WAV file through handset speaker - Done.
* Identify handset and PRESS button connections on the phone and detect states on Teensy - Done.
* RTC using a button battery - Done.
* Record message via handset speaker.  Need to wait for right angle connectors to arrive before doing the MIC, only way to test that will be to speak in to it! - Partially done, now need the bride and groom to record the message.
* Play sound when program starts up - Done.
* Play message to user to record after the beep = Done.
* Download Audacity to the PC for recording WAV files and playing them back - Done and tested.
* Program startup logic, handset not on phone, no SD card etc. No SD card - Done.
* Program logic of handset/PRESS button - In progress.
* Handle possible errors.
* Can we use the telephone dial to carry out actions - not this version. It is possible but no requirement now.
* Use [Barr Group](https://barrgroup.com/sites/default/files/barr_c_coding_standard_2018.pdf) C coding standards - In progress.
* Replace original microphone with an electret one. Waiting on manufacture of the replacement microphone housing - Done.
* Admin monitor application (WiFi) and communication from Teensy to that application (ESP32) - Done.
* Admin monitor application (Bluetooth) and communication from Teensy to that application (ESP32) - ToDo.

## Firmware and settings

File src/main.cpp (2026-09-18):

/**
 * Audio Guestbook, based on original by Playful Technology (2022)
 * https://github.com/playfultechnology/audio-guestbook - see copyright below.
 *
 * This program is designed to record messages so a micro SD card using an old GPO 706
 * rotary telephone, a Teensy 4.1, and a Teensy Audio Shield for an upcoming wedding.
 *
 * Requirements are available in the README.md file, a journal of my journey is available in the appropriately named
 * JOURNAL.md file.
 *
 * Modified AUDIO_BLOCK_SAMPLES to 256 in
 * /home/#########/.platformio/packages/framework-arduinoteensy/cores/teensy4/AudioStream.h as suggested by the audio
 * guestbook thread on the PRJC forum.
 *
 * Using clang-format addon for formatting code, CTRL+SHIFT+I to format code, put here as I know I'll forget!!
 *
 * To use RTC for file times we need to run the rtc-test program when connected to the internet (NTP time server) and
 * have the button battery connected.
 *
 * UART communications between Teensy and ESP32 which will have wifi/bluetooth access point web page to show
 * status of this applicaiton.
 *
 * Teensy command line tools are available at: ~/.platformio/packages/tool-teensy
 *   $HOME/.platformio/packages/tool-teensy/teensy_ports -L
 *   $HOME/.platformio/packages/tool-teensy/teensy_loader_cli --mcu=TEENSY41 -s -w -v firmware.hex
 *   (view logs) tail -f /var/log/syslog   
 */

/**
 * Audio Guestbook, Copyright (c) 2022 Playful Technology
 *
 * Tested using a Teensy 4.0 with Teensy Audio Shield, although should work
 * with minor modifications on other similar hardware
 *
 * When handset is lifted, a pre-recorded greeting message is played, followed by a tone.
 * Then, recording starts, and continues until the handset is replaced.
 * Playback button allows all messages currently saved on SD card through earpiece
 *
 * Files are saved on SD card as 44.1kHz, 16-bit, mono signed integer RAW audio format
 * --> changed this to WAV recording, DD4WH 2022_07_31
 * --> added MTP support, which enables copying WAV files from the SD card via the USB connection, DD4WH 2022_08_01
 *
 * Frank DD4WH, August 1st 2022
 * for a DBP 611 telephone (closed contact when handheld is lifted) & with recording to WAV file
 * contact for switch button 0 is closed when handheld is lifted
 *
 * GNU GPL v3.0 license
 *
 */

#include "play_sd_wav.h"
#include <Arduino.h>
#include <Audio.h>
#include <Bounce.h>
#include <SD.h>
#include <SPI.h>
#include <SerialFlash.h>
#include <TimeLib.h>
#include <Wire.h>

/* Defines */
#define DEBUG false       // To print to serial output or not, true == print

// Use Teensy 4.1 SD card instead of the audio boards SD card interface.
#define SDCARD_CS_PIN BUILTIN_SDCARD
#define SDCARD_MOSI_PIN 11
#define SDCARD_SCK_PIN 13

#define HANDSET_PIN 41      // Handset switch
#define PRESS_PIN 40        // PRESS switch
#define WARNING_DELAY 1000  // Play a warning sound every 'n' milliseconds
#define LED_BLINK_DELAY 1000 // Blink LED every 'n' milliseconds
#define UPDATE_DELAY 60000   // Send message to admin monitor application (ESP32) via UART every 'n' milliseconds

// set this to the hardware serial port we are going to use to connect to ESP32. Needs to be a
// higher serial port due to the audio shield taking up all the lower pins. 
// Pin 35 - Transmit, Pin 34 Receive, do not forget to connect common gnd between each device. 
#define ESP32SERIAL Serial8 

static const uint8_t morse_time_unit = 80;         // Morse code time unit, length of a dot is 1 time unit
static const uint32_t max_recording_time = 180'000; // Recording time limit (milliseconds) 
// Recording time limit (milliseconds) warning, will start to sound a beep in users ear.
static const uint32_t max_recording_time_warning = 10'000;

// 60000 = 1 min
// 120000 =  2 mins
// 180000 = 3 mins
// 240000 = 4 mins
// 600000 = 10 mins

/* Globals */
AudioPlaySdWav wave_file;              // Play 44.1kHz 16-bit PCM .WAV files
AudioInputI2S audio_input;             // I2S input from microphone on Teensy 4.0 Audio shield
AudioMixer4 mixer;                     // Allows merging several inputs to same output
AudioRecordQueue queue1;               // Create an audio buffer in memory before saving to SD
AudioSynthWaveform synth_waveform;     // To create the "beep" sound effect
AudioSynthWaveform synth_waveform_350; // To create UK dial tone
AudioSynthWaveform synth_waveform_450; // To create UK dial tone
AudioOutputI2S audio_output;           // I2S output to Speaker Out on Teensy 4.0 Audio shield
AudioConnection patchCord1(synth_waveform, 0, mixer, 0);
AudioConnection patchCord2(wave_file, 0, mixer, 1);
AudioConnection patchCord3(mixer, 0, audio_output, 0); // mixer output to speaker (L)
AudioConnection patchCord4(mixer, 0, audio_output, 1); // mixer output to speaker (R)
AudioConnection patchCord5(synth_waveform_350, 0, mixer, 2);
AudioConnection patchCord6(synth_waveform_450, 0, mixer, 3);
AudioConnection patchCord7(audio_input, 0, queue1, 0); // mic input to queue (L)
AudioControlSGTL5000 audio_shield;

// Structure for sending data to ESP32 monitor application
typedef struct __attribute__ ((packed, aligned(1))) {
    uint8_t mode;
    uint16_t recordings;
    uint64_t disk_remaining;
} status_data_t;

status_data_t audio_guestbook_data;
uint8_t sync_header[] = {0xDE, 0xAD, 0xBE, 0xEF};   // Syncronization header
// End of Teensy->ESP32 structure setup

typedef enum { // Keep track of current state of the device
    ERROR,
    INITIALISING,
    READY,
    RECORDMESSAGEPROMPT,
    RECORDING,
    PLAYING,
    LEFT_OFF_HOOK
} button_mode_t;
button_mode_t mode = INITIALISING;

typedef enum { // Keep track of dial tone state
    OFF,
    ON
} dial_tone_state_t;
dial_tone_state_t dial_tone = OFF;

float beep_volume = 0.9f; // not too loud
int led_state = LOW;      // LED state, LOW or HIGH
// static int one_second = 1000;
char filename[15]; // Filename to save audio recording on SD card
File file_object;  // The file object itself
unsigned long record_bytes_saved = 0L;
uint32_t wait_start = 0;
elapsedMillis recording_timer = 0;  // Recording timer to prevent long messages
uint16_t number_of_recordings = 0;  // Number of recordings since last started
uint64_t total_disk_size = 0;       // SD Card disk size

// Debounce on switches
Bounce phone_handset = Bounce(HANDSET_PIN, 40);
Bounce press_button = Bounce(PRESS_PIN, 40);

/* Function prototypes */
// static void play_file(const char *filename);
static void wait(unsigned int milliseconds);
static void end_beep(void);
// static void error(void);
static void sd_card_error(void);
static void blink_led(void);
static void update_admin_monitor(bool mode_changed);
static time_t get_teensy_three_time(void);
// static void print_digits(int digits);
// static void digital_clock_display(void);
// static void print_time(void);
static void sound_warning(void);
static void start_recording(void);
static void get_number_of_recordings(void);
static void continue_recording(void);
static void stop_recording(void);
static void write_out_wav_header(void);
#if DEBUG
static void print_mode(void); // for debugging only
#endif
static void dialing_tone(dial_tone_state_t on_or_off);

/**
 * @brief Program setup.
 */
void setup() {
    bool b_sd_card = false; // SD card present or not

    pinMode(LED_BUILTIN, OUTPUT);    // Orange LED on board
    digitalWrite(LED_BUILTIN, HIGH); // Glowing whilst running through setup code

    // while (!Serial) {
    //     // Wait for serial to start!
    // }

    ESP32SERIAL.begin(9600);

    delay(2000); 

    #if DEBUG
        print_mode();
    #endif

#if DEBUG
    Serial.println("Serial set up correctly");
    Serial.printf("Audio block set to %d samples\n", AUDIO_BLOCK_SAMPLES);
    Serial.println("Setting up audio and SD card");
#endif

    setSyncProvider(get_teensy_three_time); // the function to get the time from the RTC
    if (timeStatus() != timeSet) {
#if DEBUG
        Serial.println("Unable to sync with the RTC");
    } else {
        Serial.println("RTC has set the system time");
        Serial.print(hour());
        Serial.print(":");
        Serial.print(minute());
        Serial.print(":");
        Serial.println(second());
#endif
    }

    // Check connection to ESP32 has been initialised
#if DEBUG
    if (ESP32SERIAL) {
        Serial.println("ESP32SERIAL initialised");
    } else {
        Serial.println("ESP32SERIAL not initialised");
    }
#endif

    // Configure the input pins
    pinMode(HANDSET_PIN, INPUT_PULLUP);
    pinMode(PRESS_PIN, INPUT_PULLUP);

    // Reset the maximum reported by AudioMemoryUsageMax
    AudioMemoryUsageMaxReset();

    // Audio connections require memory to work. The numberBlocks input
    // specifies how much memory to reserve for audio data. Each block holds 256
    // audio samples, or approx 5.8 ms of sound.
    AudioMemory(100);

    // Comment these out if not using the audio adaptor board.
    audio_shield.enable();
    audio_shield.volume(0.6);

    // Define which input on the audio shield to use (AUDIO_INPUT_LINEIN /
    // AUDIO_INPUT_MIC)
    audio_shield.inputSelect(AUDIO_INPUT_MIC);
    audio_shield.micGain(40); // gain in dB from 0 to 63

    mixer.gain(0, 1.0f);
    mixer.gain(1, 1.0f);
    mixer.gain(2, 1.0f);
    mixer.gain(3, 1.0f);

    // Play a sound to indicate system is online
    dialing_tone(ON);

    // Init SD CARD
    SPI.setMOSI(SDCARD_MOSI_PIN);
    SPI.setSCK(SDCARD_SCK_PIN);
    if (!(SD.begin(SDCARD_CS_PIN))) {
        // Stop here, and print a message repetitively, this will cause the LED to stay lit (not that anyone can see
        // this!) and the beep tone to carry on playing to indicate an error.
        while (!b_sd_card) {
            delay(500);
            sd_card_error();
            if (SD.begin(SDCARD_CS_PIN)) {
                b_sd_card = true;
#if DEBUG
                Serial.println("SD card present");
#endif
            }
        }
    } else {
        b_sd_card = true;
#if DEBUG
        Serial.println("SD card present");
#endif
    }

    if (b_sd_card == true) {
        get_number_of_recordings(); 
    }

    delay(3000); // So we get to hear that the system is working!

#if DEBUG
    // Get the maximum number of blocks that have ever been used
    Serial.print("Max number of blocks used by Audio were: ");
    Serial.println(AudioMemoryUsageMax());
#endif
    mode = READY;

    #if DEBUG
        print_mode();
    #endif
    
    if (b_sd_card) {
        total_disk_size = SD.totalSize();
        #if DEBUG
            Serial.print("SD card size: "); Serial.println(total_disk_size);
            Serial.print("SD space used: "); Serial.println(SD.usedSize());
        #endif
        audio_guestbook_data.disk_remaining = total_disk_size - SD.usedSize();
    }

    update_admin_monitor(true);

    dialing_tone(OFF);

    // Reset the maximum reported by AudioMemoryUsageMax
    AudioMemoryUsageMaxReset();

    digitalWrite(LED_BUILTIN, LOW); // Turn LED off
}

/**
 * @brief Main loop.
 */
void loop() {
    // Read the buttons - can we move these to an interrupt?
    phone_handset.update();
    press_button.update();

    switch (mode) {
    case LEFT_OFF_HOOK:
        // Error - Phone was left off hook for too long to get here
        if (phone_handset.risingEdge()) { // Handset has been replaced
            dialing_tone(OFF);
            mode = READY;

            #if DEBUG
                print_mode();

                // Get the maximum number of blocks that have ever been used
                Serial.print("Ready: Max number of blocks used by Audio were: ");
                Serial.println(AudioMemoryUsageMax());
            #endif

            AudioMemoryUsageMaxReset();

            // Important mode change, update admin monitor
            update_admin_monitor(true);
        } else {
            // error();
            delay(3000);

            #if DEBUG
                // Get the maximum number of blocks that have ever been used
                Serial.print("Error: Max number of blocks used by Audio were: ");
                Serial.println(AudioMemoryUsageMax());
            #endif
        }
        break;

    case INITIALISING:
        // Program initialising - handset not it place etc. ?????
        break;

    case ERROR:
        // Should not get here now, using LEFT_OFF_HOOK instead
        #if DEBUG
            Serial.println("ERROR, shouldn't be here!");
            print_mode();
        #endif

        break;

    case READY:
        // Everything okay and ready to be used
        // Falling edge occurs when the handset is lifted --> GPO 706 telephone
        if (phone_handset.fallingEdge()) {
            #if DEBUG
                Serial.println("Handset lifted...");
            #endif

            mode = RECORDMESSAGEPROMPT;

            #if DEBUG
                print_mode();
            #endif
        }

        break;

    case RECORDMESSAGEPROMPT:
        // Play message to record after the beep
        delay(250); // Wait a second for handset to be brought up to ear
        wave_file.play("record.wav");
        while (!wave_file.isStopped()) {
            // Check if handset has been replaced
            phone_handset.update();
            if (phone_handset.risingEdge()) {
                wave_file.stop();
                #if DEBUG
                    Serial.println("In message prompt, set mode to ready");
                #endif

                delay(500); // Time for play back to stop
                mode = READY;

                #if DEBUG
                    print_mode();
                #endif
            }
        }

        // Check handset was not replaced above
        if (mode == RECORDMESSAGEPROMPT) {
            // Don't play the beep, user has provided own beep in record file supplied by them

            // Play beep to let user know to start speaking
            // synth_waveform.frequency(650);
            // mixer.gain(3, 1.0f);

            // synth_waveform.amplitude(0.9);
            // delay(750);
            // synth_waveform.amplitude(0); // silence beep

            #if DEBUG
                Serial.println("record.wav ended, start recording message");
            #endif

            delay(250);                  // Delay so the message start beep is not recorded - something to look at

            start_recording();

            // Important mode change, update admin monitor
            update_admin_monitor(true);
        }
        break;

    case RECORDING:
        // Has the handset been replaced or have we exceeded the recording limit
        if (phone_handset.risingEdge()) {
            stop_recording();
            end_beep();
            number_of_recordings++;
            mode = READY;

            // Important mode change, update admin monitor
            update_admin_monitor(true);

            #if DEBUG
                print_mode();
            #endif
        } else if (recording_timer >= max_recording_time) {
            #if DEBUG
                Serial.print("MAX recording time exceeded: ");
                Serial.println(recording_timer);
            #endif

            stop_recording();
            end_beep();
            number_of_recordings++;

            mode = LEFT_OFF_HOOK;

            #if DEBUG
                print_mode();
            #endif
            
            dialing_tone(ON);

            // Important mode change, update admin monitor
            update_admin_monitor(true);
        } else {
            // Check for coming near to end of max recording, sound a beep 'n' seconds before the end
            if (recording_timer > (max_recording_time - max_recording_time_warning)) {
                sound_warning();
            }

            continue_recording();
        }
        break;

    case PLAYING:
        // Playing a recording
        break;
    }

    // // Falling edge occurs when the PRESS button is pressed --> GPO 706 telephone
    // if (press_button.fallingEdge()) {
    //     #if DEBUG
    //         Serial.println("PRESS button pressed");
    //     #endif

    //     // delay(1000);
    //     // start_recording();
    // } else if (press_button.risingEdge()) { // PRESS button is released
    //     #if DEBUG
    //         Serial.println("PRESS button released");
    //     #endif

    //     delay(1000);
    //     if (mode != READY) {
    //         // stop_recording();
    //         // Serial.print("Max number of blocks used by Audio were: ");
    //         // Serial.println(AudioMemoryUsageMax());
    //     }
    // }

    blink_led();
    update_admin_monitor(false);
}

/**
 * @brief Play audio .wav file.
 */
// static void play_file(const char *filename) {
//     Serial.print("PLAYING file: ");
//     Serial.println(filename);

//     // Start playing the file.  This sketch continues to
//     // run while the file plays.
//     wave_file.play(filename);

//     // A brief delay for the library read WAV info
//     delay(25);

//     // Simply wait for the file to finish playing.
//     while (wave_file.isPlaying()) {
//     }
// }

/**
 * @brief For debugging only, print out what mode we are set to.
 */
#if DEBUG
static void print_mode(void) {
        Serial.print("Mode switched to: ");

        switch (mode) {
            case LEFT_OFF_HOOK:
                Serial.println(" LEFT_OFF_HOOK");
                break;

            case ERROR:
                Serial.println(" ERROR");
                break;

            case INITIALISING:
                Serial.println(" INITIALISING");
                break;

            case READY:
                Serial.println(" READY");
                break;

            case RECORDMESSAGEPROMPT:
                Serial.println(" RECORDMESSAGEPROMPT");
                break;

            case RECORDING:
                Serial.println(" RECORDING");
                break;

            case PLAYING:
                Serial.println(" PLAYING");
                break;

            default:
                Serial.println(" UNDEFINED");
                break;
        }
}
#endif

// WHAT DO WE DO WITH CHANGES IN BUTTONS? - TODO
/**
 * @brief Non-blocking delay, which pauses execution of main program logic, while still listening for input
 */
static void wait(unsigned int milliseconds) {
    elapsedMillis msec = 0;

    if (mode == INITIALISING) { // no need for button checking here during initialisation
        while (msec <= milliseconds) {
            // Do nothing but wait
        }
    } else {
        while (msec <= milliseconds) {
            // Currently do nothing but wait
        }

        // while (msec <= milliseconds) {
        //     phone_handset.update();
        //     press_button.update();
        //     if (phone_handset.fallingEdge()) {
        //         Serial.println("WAIT: Handset lifted");
        //     }
        //     if (press_button.fallingEdge()) {
        //         Serial.println("WAIT: PRESS button pressed");
        //     }

        //     if (phone_handset.risingEdge()) {
        //         Serial.println("WAIT Handset replaced");
        //     }
        //     if (press_button.risingEdge()) {
        //         Serial.println("WAIT: PRESS button released");
        //     }
        // }
    }
}

/**
 * @brief Play a warning to the user that recording time is coming to the end
 */
static void sound_warning(void) {
    static unsigned long previousWarningMillis;
    unsigned long timeNow = millis();

    if (timeNow - previousWarningMillis >= WARNING_DELAY) {
        previousWarningMillis = timeNow;

        // Play very short warning beep
        synth_waveform_450.frequency(450);
        synth_waveform_450.amplitude(0.3);
        delay(50);
        synth_waveform_450.amplitude(0); // silence beep
    }
}

/**
 * @brief Play a beep to indicate end of recording.
 */
static void end_beep(void) {
    synth_waveform.frequency(523.25);
    synth_waveform.amplitude(beep_volume);
    wait(250);
    synth_waveform.amplitude(0);
    wait(250);
    synth_waveform.amplitude(beep_volume);
    wait(250);
    synth_waveform.amplitude(0);
    wait(250);
    synth_waveform.amplitude(beep_volume);
    wait(250);
    synth_waveform.amplitude(0);
    wait(250);
    synth_waveform.amplitude(beep_volume);
    wait(250);
    synth_waveform.amplitude(0);
}

/**
 * @brief Play morse code.
 */
// static void error(void) {
//     // Morse code timings
//     uint8_t dot = morse_time_unit; // milliseconds
//     uint16_t dash = dot * 3;
//     uint8_t symbol_space = dot;
//     uint16_t letter_space = dot * 3;
//     uint16_t word_space = dot * 7;

//     // dots
//     synth_waveform.amplitude(beep_volume);
//     synth_waveform.frequency(800);
//     wait(dot);
//     synth_waveform.amplitude(0);
//     wait(symbol_space);
//     synth_waveform.amplitude(beep_volume);
//     wait(dot);
//     synth_waveform.amplitude(0);
//     wait(symbol_space);
//     synth_waveform.amplitude(beep_volume);
//     wait(dot);
//     synth_waveform.amplitude(0);

//     wait(letter_space);

//     // 3 dashes
//     synth_waveform.amplitude(beep_volume);
//     wait(dash);
//     synth_waveform.amplitude(0);
//     wait(symbol_space);
//     synth_waveform.amplitude(beep_volume);
//     wait(dash);
//     synth_waveform.amplitude(0);
//     wait(symbol_space);
//     synth_waveform.amplitude(beep_volume);
//     wait(dash);
//     synth_waveform.amplitude(0);

//     wait(letter_space);

//     // dots
//     synth_waveform.amplitude(beep_volume);
//     wait(dot);
//     synth_waveform.amplitude(0);
//     wait(symbol_space);
//     synth_waveform.amplitude(beep_volume);
//     wait(dot);
//     synth_waveform.amplitude(0);
//     wait(symbol_space);
//     synth_waveform.amplitude(beep_volume);
//     wait(dot);
//     synth_waveform.amplitude(0);

//     wait(word_space);
// }
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

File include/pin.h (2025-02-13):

// From: https://github.com/TeensyUser/doc/blob/master/examples/GPIO/pinList/pin.h
#ifndef PIN_H
#define PIN_H

#include "core_pins.h"

class Pin
{
public:
    inline Pin(unsigned pin, unsigned Mode = INPUT);
    unsigned getPinNr() const { return pinNr; }
    unsigned getBitNr() const { return bitNr; }
    unsigned getGpioNr() const { return gpioNr; }

protected:
    const unsigned pinNr;
    const uintptr_t pinCfg;
    const unsigned gpioNr;
    const unsigned bitNr;
};

#if defined(KINETISK) || defined(KINETISL)
Pin::Pin(unsigned pin, unsigned mode)
    : pinNr(pin),
      pinCfg((uintptr_t)digital_pin_to_info_PGM[pin].config), // address of pin config register
      gpioNr((pinCfg - (uintptr_t)&PORTA_PCR0) / 0x1000),     // cfg base addresses are 4kB aligned staring with PORTA_PCR0
      bitNr((pinCfg & 0xFFF) / 4)                             // each bit has to 4 consecutive 32bit cfg registers
{
    pinMode(pinNr, mode);
}

#elif defined(ARDUINO_TEENSY40) || defined (ARDUINO_TEENSY41) || defined (ARDUINO_TEENSY_MICROMOD)

Pin::Pin(unsigned pin, unsigned mode)
    : pinNr(pin),
      pinCfg((uintptr_t)digital_pin_to_info_PGM[pinNr].reg),        // address of pin config register
      gpioNr((pinCfg - (uintptr_t)&IMXRT_GPIO6) / 0x4000 + 6),      // cfg base addresses are 4kB aligned staring with PORTA_PCR0
      bitNr(__builtin_ffs(digital_pin_to_info_PGM[pinNr].mask) - 1) // each bit has to 4 consecutive 32bit cfg registers
{
    pinMode(pinNr, mode);
}

#endif
#endif /* PIN_H */

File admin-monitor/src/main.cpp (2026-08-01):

/** 
 * This is the admin monitor for the audio guestbook. It runs on an ESP32 and has a wi-fi
 * access point (password protected) so admin user can monitor how the guestbook is doing. 
 * 
 * Connection between the teensy and the esp32 will be via serial, receive only for the ESP,
 * do not want anything/one messing with the guestbook. 
*/
#include <Arduino.h>

// Load Wi-Fi library
#include <AsyncTCP.h>
#include <ESPAsyncWebServer.h>
#include <WiFi.h>

// Fix access point not working
#include "esp_wifi.h"
#include "esp_bt.h"

#include "../include/index.h"
#include "../include/config.h"

#include <HardwareSerial.h>
#include <inttypes.h>

// the setup function runs once when you press reset or power the board
#ifdef RGB_BUILTIN
#undef RGB_BUILTIN
#endif
#define RGB_BUILTIN 48

#define DEBUG false      // to turn on/off printf statements

static String processor(const String &var);
static void send_events_to_web_client(void);

// Teensy UART communications setup
// Define the RX pin for Serial
// Using GPIO7 for uart, default tx/rx pins interact with access point wifi for some reason!
#define RX_TEENSY 7
#define TEENSY_BAUD_RATE 9600
HardwareSerial teensy_serial(0);

typedef struct __attribute__((packed, aligned(1))) {
    uint8_t mode;
    uint16_t recordings;
    uint64_t disk_remaining;
} teensy_data_t;

teensy_data_t audio_guestbook_data;

typedef enum { // State of the audio guestbook
    ERROR,
    INITIALISING,
    READY,
    RECORDMESSAGEPROMPT,
    RECORDING,
    PLAYING,
    LEFT_OFF_HOOK
} button_mode_t;
// end of teensy information setup

// Set web server port number to 80
AsyncWebServer server(80);

// Create an Event Source on /events
AsyncEventSource events("/events");

// Set your Static IP address for hotspot
IPAddress hotspot_local_ip(172, 20, 10, 10);
IPAddress hotspot_gateway(172, 20, 10, 0);
IPAddress hotspot_subnet(255, 255, 255, 240);

// Define custom IP, Gateway, and Subnet for local access point
IPAddress ap_local_ip(192, 168, 10, 1);
IPAddress ap_gateway(192, 168, 10, 1);
IPAddress ap_subnet(255, 255, 255, 0);

// Variables
unsigned long last_time = 0;
char runtime_buffer[10];


void setup() {

    neopixelWrite(RGB_BUILTIN, 0, 0, 0); // Turn off LED

    if (DEBUG) {
       Serial.begin(115200);

        delay(5000);  // Wait for serial to start

    
        Serial.println(F("\n##################################"));
        Serial.println(F("ESP32 Information:"));
        Serial.printf("Internal Total Heap %d, Internal Used Heap %d, Internal Free Heap %d\n", ESP.getHeapSize(),
                    ESP.getHeapSize() - ESP.getFreeHeap(), ESP.getFreeHeap());
        Serial.printf("Sketch Size %d, Free Sketch Space %d\n", ESP.getSketchSize(), ESP.getFreeSketchSpace());
        Serial.printf("SPIRam Total heap %d, SPIRam Free Heap %d\n", ESP.getPsramSize(), ESP.getFreePsram());
        Serial.printf("Chip Model %s, ChipRevision %d, Cpu Freq %dMHz, SDK Version %s\n", ESP.getChipModel(),
                    ESP.getChipRevision(), ESP.getCpuFreqMHz(), ESP.getSdkVersion());
        Serial.printf("Flash Size %d, Flash Speed %d\n", ESP.getFlashChipSize(), ESP.getFlashChipSpeed());
        Serial.println(F("##################################\n\n"));
    }
 
    // Connect to Wi-Fi network with SSID and password
    if (DEBUG) {
        Serial.println("Setting AP (Access Point)…");
    }

    // Connect to phone's hotspot connect, access point not working!
    // WiFi.config(hotspot_local_ip, hotspot_gateway, hotspot_subnet);
    // WiFi.mode(WIFI_STA); //Optional
    // WiFi.begin(HOTSPOT_SSID, HOTSPOT_PASSWORD);
    
    // if (DEBUG) {
    //     Serial.println("\nConnecting");
    // }

    // while(WiFi.status() != WL_CONNECTED){
    //     if (DEBUG) {
    //         Serial.print(".");
    //     }

    //     delay(100);
    // }

    // if (DEBUG) {
    //     Serial.println("\nConnected to the WiFi network");
    //     Serial.print("Local ESP32 IP: ");
    //     Serial.println(WiFi.localIP());
    // }

    // // Set to off state to start as access point
    WiFi.disconnect(true);
    WiFi.mode(WIFI_OFF);

    // Disable bluetooth as we're not using it
    esp_bt_controller_disable();
    // Lower wifi power to help with over heating
    esp_wifi_set_max_tx_power(WIFI_POWER_11dBm);

    // Set to access point mode
    WiFi.mode(WIFI_AP);
    // Set up custom IP address
    WiFi.softAPConfig(ap_local_ip, ap_gateway, ap_subnet);

    // Taken from config.h
    bool result = WiFi.softAP(SSID, WIFI_PASSWORD);
    if (DEBUG) {
        Serial.print("Set up access point result = ");
        Serial.println(result);

        Serial.print("Connecting to: ");
        Serial.println(SSID);

        IPAddress IP = WiFi.softAPIP();
        Serial.print("AP IP address: ");
        Serial.println(IP);
    }
    
    // Handle Web Server
    server.on("/", HTTP_GET, [](AsyncWebServerRequest *request){
        request->send(200, "text/html", MAIN_page, processor); });

    // Handle Web Server Events
    events.onConnect([](AsyncEventSourceClient *client) {
        if (client->lastId()) {
            if (DEBUG) {
                Serial.printf("Client reconnected! Last message ID that it got is: %u\n", client->lastId());
            }
        }
        // send event with message "hello!", id current millis
        // and set reconnect delay to 1 second
        client->send("hello!", NULL, millis(), 10000);
    });
    server.addHandler(&events);
    server.begin(); // Start server

    if (DEBUG) {
        Serial.println("HTTP server started");
        Serial.println("");
    }

    // Set up run time buffer to 5 seconds, waiting time above!
    sprintf(runtime_buffer, "%02d:%02d:%02d", 0, 0, 5);

    // Set up UART communications (UART0) to Teensy. Rx only will be used,
    // there will be no transmit to the Teensy
    teensy_serial.begin(TEENSY_BAUD_RATE, SERIAL_8N1, RX_TEENSY);

    audio_guestbook_data.disk_remaining = 0;
    audio_guestbook_data.recordings = 0;
    audio_guestbook_data.mode = INITIALISING;
}
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

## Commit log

2025-01-29 Added board pictures
2025-02-03 Handset and PRESS button pins set
2025-02-09 Fixed beeps issue, added RTC
    [main.cpp]
2025-02-09 Changed switch pins on Teensy
2025-02-13 Error beeps now morse code
    [main.cpp]
2025-02-13 Added wiring diagram
2025-02-14 Fixing logic and add build options
    [main.cpp]
2025-02-14 Add button test project
2025-02-14 Fix morse code speed
    [main.cpp]
2025-02-15 Working on recording logic
    Excess length recordings not erroring for some reason.
    [main.cpp]
2025-02-17 ESP32 admin project created
2025-02-18 STL of replacement microphone holder
    Unsure if this is the final version until it has been printed and testing in place.
    [GPO706-Electret-Mic.stl]
2025-02-20 Update from button-test project
2025-03-31 Initial commit
    Tinkercad version of the 3D model
    [GPO706-tinkercad.stl]
2025-08-29 Remove ESP32 for now
2025-09-29 UART to admin monitor working
2025-10-17 New wiring diagram
2025-11-03 Power box update
    [AG Power Box Lid.stl, AG Power Box.stl]
2025-11-03 Power connection box update
2025-11-16 Change CPU freq to 80MHz to save power
2026-07-28 Fix access point ip address, add phone hotspot capability.
    [main.cpp]
2026-08-01 Add error mode LEFT_OFF_HOOK
    [main.cpp]
2026-11-09 Remove ESP32
